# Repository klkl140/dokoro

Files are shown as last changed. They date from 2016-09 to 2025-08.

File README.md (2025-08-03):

# dokoro
a roboter for playing cards

##idea:
This device should replace a normal player.
It will be possible to play doko without having 4 people at the same table.
The device could act like a normal player, playing with its own intelligence or as an interface for an external player, for example sitting in timbuktu.
In addition it can be used for many different card games. Only a software problem.....

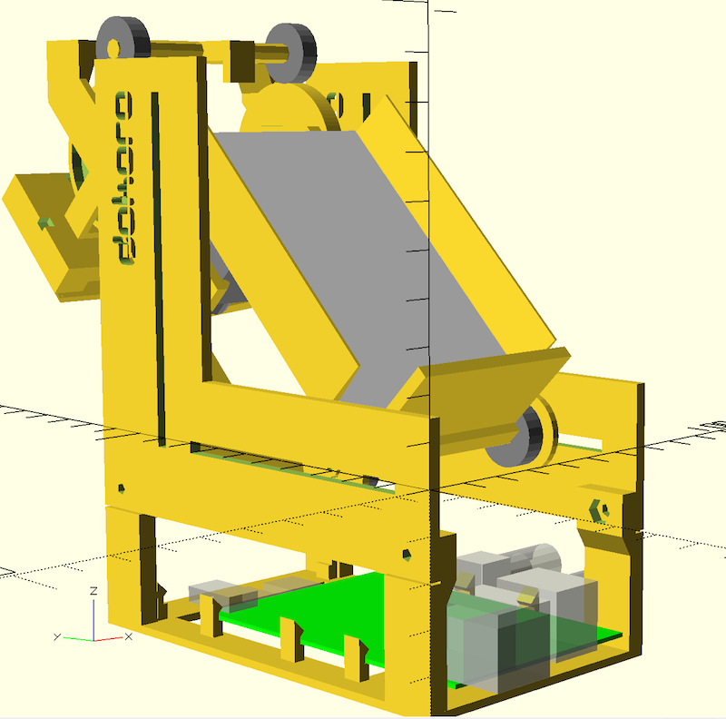
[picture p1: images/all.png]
dokoro openscad


##how it should work:
A human player is distributing the cards. The **dokoro** gets its cards placed in the cardholder.
For scanning these cards it has minimalistic hardware. One motor, one servo and a camera. The cards are moved in front of the camera one by one and an image-recognition is used. [Here](images/dokoroAnimation.mp4) a small animation.

After all the cards are recognized the play could start. A camera watches the playfield. This second view might be part of the first camera view using a mirror(?).
For the intelligence the project [FreeDoko](http://free-doko.sourceforge.net/de/FreeDoko.html) is planed to be used.

##the OpenSCAD construction uses:

###public libraries

[ParametricHerringboneGears.scad](https://github.com/beckdac/PARA/blob/master/ParametricHerringboneGears.scad)  
[pibase.scad](https://github.com/guyc/pi-box/blob/master/pibase.scad)  
[Font/font_DesignerBlock_lo.scad](https://github.com/QuackingPlums/QP_OpenSCAD_lib/blob/master/Makerbot%20font%20(Thingiverse%2022730)/font_DesignerBlock_lo.scad)  
[ISOThreadCust.scad](http://www.thingiverse.com/thing:311919)

###included files

CameraAdapter.scad, based on [piCameraMicroscopeAdapter.scad](https://github.com/luisibanez/ShapesFor3DPrinting/blob/master/OpenSCAD/piCameraMicroscopeAdapter.scad)  
9g_servo.scad  

##additional used parts:

* 4 ball-bearing 625	(at the rubber bands)
* 2 ball-bearing 683	(at the driving axis)
* 2 rubber-bands 130*4mm 
* [gear motor](http://www.ebay.de/itm/DC-1-5-12V-200rpm-Getriebe-Motor-elektrisch-Electric-Metal-Geared-Motor-3v-6v-9v-/231526128396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) 12V, 200 U/min
* [mini servo 9g SG90](http://www.ebay.de/itm/ELE-2x-Micro-Mini-Servo-SG90-RC-Servo-9g-Kabel-23cm-Neu-/222005349852) with some parts
* a metal axis 70*3mm
* a M3*76mm threaded rod
* Raspberry Pi with camera
* electronic for driving the motor and the servo (adafruit motor HAT)
* some screws and washers
	* 2* M3*8 + nut 		(at base frontside)
	* 2* M3*12 + nut 	(at the base backside)
	* 4* M3*6 countersunk +nuts (at the cardholder)
	* M3*25 + nut 		(at the camera arm)
	* 4* threaded rods M3*20 (at gears and driving wheels)
	* 2* washers M3 (at driving axis, between motorholder and driving wheel)

##electronics:
An Adafruit Motor HAT [circuit](https://cdn-learn.adafruit.com/assets/assets/000/022/655/original/raspberry_pi_schem1.png?1422045515) [instructions](https://learn.adafruit.com/adafruit-dc-and-stepper-motor-hat-for-raspberry-pi) is used for driving the DC-motor and the servo.
The DC motor is connected to M3, the servo is driven by the PWM of the Raspi with an aditional 5V regulator.

##other ideas:
A monitor could be used to show informations, a speaker for giving _valuable comments_. When the dokoro is used as an interface, these parts could be used to get a real connection to the remote player.  
The main focus is an easy to use device without any unnecessary interface. Speach recognition could be a good way to make some necessary inputs like anouncing solos, wedding, ... 

##current status:
The hardware seems to work. Cards could be moved by the driven rubber bands. The servo is mechanically able to move the cards and the whole flow of scanning the cards seems possible.  
FreeDoko could be compiled and the place of the missing interface is clear.  
Next step is connecting the raspbi to drive motor and servo.
Im searching for help in every project part. Help is given when someone tries to build his own example for development.  
__There is no working example available (up to now).__  

##challenges:
The reliability of the mechanic is not easy. All moving parts are constructed with ball bearings. The separation of cards might be difficult, especially when dirty cards will be allowed.  
Getting the interface to the Freedoko source might be easy. There is a network-player option which matches perfectly. The server has to the changed in the way that cards are not in the program but on the table.  
The use as an interface for external players will be a big place for software development.   

##licensing
The project is licenced using GPL2.

Enjoy it.... Klaus

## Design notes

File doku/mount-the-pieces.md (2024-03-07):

Start mounting cardholder (kartenauflage') to the (halterUnten) using 2x M3x6 countersunk screws and 2 nuts. 
Do the same with the motormount (halterOben)

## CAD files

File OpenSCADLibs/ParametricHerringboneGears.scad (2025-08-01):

// für den Dokoro verändert, das Original war https://www.thingiverse.com/thing:6544/files

// OpenSCAD Herringbone Wade's Gears Script
// (c) 2011, Christopher "ScribbleJ" Jansen
//
// Thanks to Greg Frost for his great "Involute Gears" script.
//
// Licensed under the BSD license.
include <MCAD/involute_gears.scad> 


// hier die Werte für die Vorschau
// WHAT TO GENERATE?
generate = 0;    // GENERATE BOTH GEARS FOR VIEWING
// generate = 1;    // GENERATE STEPPER GEAR FOR PRINTING
// generate = 2;    // GENERATE DRIVE GEAR FOR PRINTING

// OPTIONS COMMON TO BOTH GEARS:
distance_between_axels = 20;        // der Abstand zwischen den beiden Achsen
gear_h = 10;                        // die Breite des Zahnrads
gear_shaft_h = 4;                   // die zusaetzliche Breite des Schafts


// GEAR1 (SMALLER GEAR, STEPPER GEAR) OPTIONS:
// It's helpful to choose prime numbers for the gear teeth.
gear1_teeth = 10;                   // Anzahl der Zaehne des ersten Zahnrads
gear1_shaft_d = 3;  			    // die Bohrung fuer die Achse
// gear1 shaft assumed to fill entire gear.
// gear1 attaches by means of a captive nut and bolt (or actual setscrew)
gear1_setscrew_offset = 2.5;		// der Abstand der Befestigungsbohrung von der Shaft-Seite
gear1_setscrew_d      = 2.4;        // der Durchmesser der Bohrung		
// evtl eine Mutter fuer die Befestigungsschraube
gear1_captive_nut_d   = 0;      // das kleine Zahnrad hat keine Mutter. zu wenig Platz
gear1_captive_nut_r   = gear1_captive_nut_d/2;
gear1_captive_nut_h   = 0;    // Dicke M3 Mutter

// GEAR2 (LARGER GEAR, DRIVE SHAFT GEAR) OPTIONS:
gear2_teeth = 16;
gear2_shaft_d = 3;
// gear2 has settable outer shaft diameter.
gear2_shaft_outer_d   = 16;

// gear2 has a hex bolt set in it, is either a hobbed bolt or has the nifty hobbed gear from MBI on it.
gear2_bolt_hex_d      = 0;       //ohne sechskant
// gear2_bolt_sink: How far down the gear shaft the bolt head sits; measured as distance from drive end of gear.
gear2_bolt_sink       = 15;      //		
// gear2's shaft is a bridge above the hex bolt shaft; this creates 1/3bridge_helper_h sized steps at top of shaft to help bridging.  (so bridge_helper_h/3 should be > layer height to have any effect)
bridge_helper_h=3;

gear2_rim_margin = 0;
gear2_cut_circles  = 0;     // sind im Zahnrad-Körper Bohrungen zur Gewichtsreduzierung?

// gear2 setscrew option; not likely needed.
gear2_setscrew_offset = gear1_setscrew_offset;
gear2_setscrew_d      = gear1_setscrew_d;
// captive nut for the setscrew
gear2_captive_nut_d   = 5.6;      // Breite M3 Mutter
gear2_captive_nut_r   = gear1_captive_nut_d/2;
gear2_captive_nut_h   = 2.6;    // Dicke M3 Mutter

// Tolerances for geometry connections.
AT=0.02;
ST=AT*2;
TT=AT/2;

module bridge_helper(){
	difference(){
		translate([0,0,-bridge_helper_h/2])
            cylinder(d=gear2_bolt_hex_d+TT, h=bridge_helper_h+TT,$fn=6,center=true);
		translate([0,0,-bridge_helper_h/2])
            cube([gear2_bolt_hex_d+ST, gear2_shaft_d, bridge_helper_h+AT], center=true);
	}
}


module gearsbyteethanddistance(t1=13,t2=51, d=60, teethtwist=1, which=1){
	//cp = 360*d/(t1+t2);
    cp = 2*pi*d/(t1+t2);    // kl involute_gears has changed

	g1twist = 360 * teethtwist / t1;
	g2twist = 360 * teethtwist / t2;

	g1p_d  =  t1 * cp / 180;
	g2p_d  =  t2 * cp / 180;
	g1p_r   = g1p_d/2;
	g2p_r   = g2p_d/2;

	echo(str("Your small ", t1, "-toothed gear will be ", g1p_d, "mm across (plus 1 gear tooth size) (PR=", g1p_r,")"));
	echo(str("Your large ", t2, "-toothed gear will be ", g2p_d, "mm across (plus 1 gear tooth size) (PR=", g2p_r,")"));
	echo(str("Your minimum drive bolt length (to end of gear) is: ", gear2_bolt_sink+bridge_helper_h, "mm and your max is: ", gear_h+gear_shaft_h, "mm."));
	echo(str("Your gear mount axles should be ", d,"mm (", g1p_r+g2p_r,"mm calculated) from each other."));
    
    if(which == 1){ // GEAR 1 (das kleinere)
		difference(){
            union(){
                translate([0,0,(gear_h/2) - TT])
                    // der Teil des Zahnrads mit dem Schaft
                    gear(	twist = g1twist, 
                        number_of_teeth=t1,
                        circular_pitch=cp, 
                        gear_thickness = gear_shaft_h + (gear_h/2)+AT, 
                        rim_thickness = (gear_h/2)+AT, 
                        rim_width = 0,
                        hub_thickness = (gear_h/2)+AT, 
                        hub_diameter = 0,   //kl war hub_width das gibt es aber nicht mehr
                        bore_diameter=0); 
        
                translate([0,0,(gear_h/2) + AT])
                rotate([180,0,0]) 
                    // der zweite Teil des Zahnrads
                    gear(	twist = -g1twist, 
                        number_of_teeth=t1, 
                        circular_pitch=cp, 
                        gear_thickness = (gear_h/2)+AT, 
                        rim_thickness = (gear_h/2)+AT, 
                        hub_thickness = (gear_h/2)+AT, 
                        bore_diameter=0); 
            }
			//DIFFERENCE:
			//shafthole
			translate([0,0,-TT]) 
				cylinder(d=gear1_shaft_d, h=gear_h+gear_shaft_h+ST,$fn=10);

			//setscrew shaft
			translate([0,0,gear_h+gear_shaft_h-gear1_setscrew_offset])
				rotate([0,90,0])
				cylinder(d=2, h=10);    // h war g1p_r, das stimmt aber nicht mehr

			//setscrew captive nut
			translate([5.5/2, 0, gear_h+gear_shaft_h-gear1_captive_nut_r-gear1_setscrew_offset]) 
				translate([0,0,(gear1_captive_nut_r+gear1_setscrew_offset)/2])
					cube([gear1_captive_nut_h, gear1_captive_nut_d, gear1_captive_nut_r+gear1_setscrew_offset+ST],center=true);

        }
	} else {    //which!=1
		// GEAR 2
		difference(){
            union(){
                translate([0,0,(gear_h/2) - TT])
                    gear(	twist = -g2twist, 
                        number_of_teeth=t2, 
                        circular_pitch=cp, 
                        gear_thickness = gear_shaft_h + (gear_h/2)+AT, 
                        rim_thickness = (gear_h/2)+AT, 
                        rim_width = gear2_rim_margin,
                        hub_diameter = gear2_shaft_outer_d,
                        hub_thickness = (gear_h/2)+AT, 
                        bore_diameter=0,
                        circles = gear2_cut_circles); 
        
                translate([0,0,(gear_h/2) + AT])
                rotate([180,0,0]) 
                    gear(	twist = g2twist, 
                        number_of_teeth=t2, 
                        circular_pitch=cp, 
                        gear_thickness = (gear_h/2)+AT, 
                        rim_thickness = (gear_h/2)+AT, 
                        rim_width = gear2_rim_margin,
                        hub_diameter = gear2_shaft_outer_d,
                        hub_thickness = (gear_h/2)+AT, 
                        bore_diameter=0,
                        circles = gear2_cut_circles); 
            }
			//DIFFERENCE:
			//shafthole, fuer die Achse
			translate([0,0,-TT]) 
				cylinder(d=gear2_shaft_d, h=gear_h+gear_shaft_h+ST, $fn=10);

			//setscrew shaft, die Befestigungsschraube
			translate([0,0,gear_h+gear_shaft_h-gear2_setscrew_offset])
				rotate([0,90,0])
				cylinder(d=gear2_setscrew_d, h=gear2_shaft_outer_d);

			//setscrew captive nut
			translate([(gear2_shaft_outer_d)/4, 0, gear_h+gear_shaft_h-gear2_captive_nut_r-gear2_setscrew_offset]) 
				translate([0,0,(gear2_captive_nut_r+gear2_setscrew_offset)/2])
					cube([gear2_captive_nut_h, gear2_captive_nut_d, gear2_captive_nut_r+gear2_setscrew_offset+ST],center=true);

			//trim shaft
			difference(){
				translate([0,0,gear_h+AT]) cylinder(h=gear_shaft_h+ST, r=g2p_r);
				translate([0,0,gear_h])	cylinder(h=gear_shaft_h, d=gear2_shaft_outer_d);
			}

			//hex bolt shaft
			translate([0,0,-TT]) cylinder(d=gear2_bolt_hex_d, h=gear_h+gear_shaft_h-gear2_bolt_sink+AT,$fn=6);

		}

		// hex bolt shaft bridge aid.
		translate([0,0,gear_h+gear_shaft_h-gear2_bolt_sink])
			bridge_helper();
		translate([0,0,gear_h+gear_shaft_h-gear2_bolt_sink+bridge_helper_h/3])
			rotate([0,0,60]) bridge_helper();
		translate([0,0,gear_h+gear_shaft_h-gear2_bolt_sink+((bridge_helper_h/3)*2)])
			rotate([0,0,-60]) bridge_helper();
	}
}

t1 = gear1_teeth;
t2 = gear2_teeth;
cp = 360*distance_between_axels/(t1+t2);
g1p_d  =  t1 * cp / 180;
g2p_d  =  t2 * cp / 180;
g1p_r   = g1p_d/2;
g2p_r   = g2p_d/2;

if(generate != 2){  // 0 oder 1
	translate([-g1p_r,0,0])gearsbyteethanddistance(t1 = gear1_teeth, t2=gear2_teeth, d=distance_between_axels, which=1);
}
if(generate != 1){   // 0 oder 2
	translate([g2p_r,0,0])gearsbyteethanddistance(t1 = gear1_teeth, t2=gear2_teeth, d=distance_between_axels, which=2);
}

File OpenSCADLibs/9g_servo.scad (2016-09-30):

drehachseR = 2.35;
servoX = 23;
servoY = 12.5;
servoZ = 22.5;

offsetBefestigungZ=4;   // wie weit ist die Unterkante der Befestigungsplatte von der Mittelachse entfernt
befestigungZ = 2.7;

module 9g_motor(){
	difference(){			
		union(){
			color("Gray") cube([servoX,servoY,servoZ], center=true);
			befestigungZ = 2.7;
            color("Gray") translate([0,0,offsetBefestigungZ+befestigungZ/2])
                cube([32,12,befestigungZ], center=true);
			color("Gray") translate([5.5,0,2.75]) cylinder(r=6, h=25.75, $fn=20, center=true);
			color("Gray") translate([-.5,0,2.75]) cylinder(r=1, h=25.75, $fn=20, center=true);
			color("Gray") translate([-1,0,2.75]) cube([5,5.6,24.5], center=true);		
			color("white") translate([5.5,0,3.65]) cylinder(r=2.35, h=29.25, $fn=20, center=true);
		}
		// die Abschrägung gibt es nicht immer
        //translate([10,0,-11]) rotate([0,-30,0]) cube([8,13,4], center=true);
		for ( hole = [14,-14] ){
			translate([hole,0,5]) cylinder(r=2.2, h=4, $fn=20, center=true);
		}	
	}
}

module 9g_arm(laenge,winkel){
    dicke = 3;
    rAchse = 4;
    rEnde = 2;
    #translate([5.4,0,16])rotate([0,0,winkel]){
        difference(){
            union(){
                translate([0,0,-2]) cylinder(r=rAchse, h=dicke+2);
                linear_extrude(height = dicke, convexity = 10)
                    polygon(points=[[0,rAchse],[0,-rAchse],[laenge,rEnde],[laenge,-rEnde]]
                        , paths=[[0,1,3,2]]);
                translate([laenge,0,0]) cylinder(r=rEnde, h=dicke);
            }
            // die Achse
            translate([0,0,-2.1]) cylinder(r=drehachseR, h=2);
            // das Loch zur Befestigung der Hebelstange
            translate([laenge,0,-.1]) cylinder(d=1.5, h=dicke+.2);
        }
    }
}

module 9g_holder(){
    luft = .3;
    dicke = 3;
    hoehe = servoZ; // der Halter ist so hoch wie das Servo
    naseY = 3.3;    // soll etwas unter Spannung sein, war 3.5
    difference(){
        union(){
            // lange Seite
            translate([-servoX/2-luft,servoY/2+luft,servoZ/2-hoehe])
                cube([servoX+2*luft,dicke,hoehe]);
            // kurze Seiten
            seiteY = servoY+dicke+luft+naseY-1; // jetzt 1mm kürzer
            hoeheS=hoehe-7; //die Federklammern sind auf der ganzen Höhe zu fest.
                            //das Kabel muss auch raus geführt werden
            for(x=[-servoX/2-dicke-luft, servoX/2+luft]){
                translate([x,-servoY/2-naseY+1,servoZ/2-hoeheS]) cube([dicke,seiteY,hoeheS]);
            }
            // die Haltenasen
            dicke2=dicke*.9;   // war 1.1
            for(x=[servoX/2+luft,-servoX/2-luft]){
                //Y jetzt 1mm kuerzer (+1)
                translate([x,-servoY/2-naseY+1,servoZ/2-hoeheS])
                    rotate([0,0,45]) cube([dicke2,dicke2,hoeheS]);
            }
        }
        // der Schlitz für die Befestigung
        schlitzZ = befestigungZ+luft;
        schlitzY = servoY+naseY+.1;
        gesamtX = servoX+2*luft+2*dicke;
        gesamtY = dicke+luft+servoY+naseY;
        translate([-gesamtX/2-.1,-schlitzY+servoY/2,offsetBefestigungZ])
            cube([gesamtX+.2,schlitzY,schlitzZ]);
    }
}

9g_motor();
9g_arm(laenge=20,winkel=90);
9g_holder();

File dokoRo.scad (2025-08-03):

// der DoppelKopfRoboter
// (c) Klaus Kloos 160630
//
// die 0-Achse liegt in der Mitte der horizontalen Winkelverstellung

use <pibase.scad>                                   // pi board und halter
use <OpenSCADLibs/ParametricHerringboneGears.scad>  // erzeugt die Zahnräder aufgrund von Zahnanzahl und Abstand
use <OpenSCADLibs/servo9g.scad>
use <OpenSCADLibs/CameraAdapter.scad>               // fuer die Raspberry-Kamera
use <Font/font_DesignerBlock_lo.scad>
use <ISOThreadCust.scad>
use <MCAD/bearing.scad>

// neu, noch nicht gedruckt
//
// was fehlt noch?
// -Kabelbefestigung
//
// was soll gemalt werden?
paintAll3D = 0;                         // alle Teile an ihren Positionen evtl mit Animation
paintAll2D = 0;                         // dies kann mit einem Laser gemacht werden

if(!paintAll3D){         // hier kommen die einzelnen Teile für die Fertigung
    //seitenwand();						// 2* die Seiten
    //cardholder();                     // kartenauflage, hier liegen die Karten
    //separierer(separierer);
    //scheibeHalterUnten();             // 2* neben den Kugellagern zur Führung des Gummis
    rotate([180,0,0]) halterUnten();  // mit den unteren beiden Kugellagern
    //rotate([0,180,0]) motorKlemme(); // hiermit wird der Motor befestigt
    //antriebsRad();  // 2* die oberen Antriebsräder
    //halterOben(0);                    // ohne Antrieb
    //bothGears();                      // beide Zahnräder, fürs Drucken Auflösung einstellen!
    //rotate([45,0,0])anpressrolle();   // der mit dem Servo bewegte Greifer
    //raspbiHalter();                   // der Halter für den Raspberry
    //kameraHalter();                   // Kamera fuer den Blick auf die Karten
	//piCameraBackCover(-0.2);	        // der Schiebedeckel zur Kamera
    //motor();                          // Dummy des Motors, muss nicht gedruckt werden
}

// Animation
t_cardUp = .3;                      // die Zeit in der die Karte nach oben fährt
t_drehung = .5;                     // nach dieser Zeit ist die Drehung fertig
t_cardUp2 = .7;                     // die zweite Bewegung der Karte

cardRaw = [59, 90, 0.5];            // eine Spielkarte
card = [cardRaw.x+1,cardRaw.y+3];   // mit ein wenig Spiel

gummiB = 4+.5;                      // Breite des Gummies + Freiraum
gummiD = 1;                         // die Dicke des Gummis

swSchenkelH = 35;                   // die Breite des horizontalen Seitenwand-Schenkels, in der Mitte der Schlitz
swAddY = 5;                         // auf der Seite der Antriebsräder etwas breiter für die Schrift
swSchenkelV = swSchenkelH+swAddY;   // und damit der Servohebel geführt wird
// die Abmasse der flach liegende Seitenwand
seitenwand = [card.y+swSchenkelH/2+swAddY   // horizontal    
    , card.y+swSchenkelH/2                  // vertical
    , 3];                                   // dicke

auflageD = 3;                       // cardholder und der obere Halter
breiteStegUnten = 15;
KL625frei = bearingWidth(model=625)+1; // ein wenig Spiel
rolleObenD = 38;                    // Duchmesser der Antriebsrolle oben
rolleObenB = gummiB+.5;             // die Breite
bohrungHalter = 3.5;                // fuer beide Halter, war 3
bohrungHalterX = 12;                // jeweils der Abstand vom Rand
screwholeBottomY = 10;
screwholeTopY = 81;
achseAntrieb = 3;                   // muss auch in ParametricHerringboneGears eingestellt werden
motorHalter=[17,20];                // der Bock an dem der Motor befestigt wird [x,y]
motorHalterBohrungD=2.5;            // die Befestigung des oberen Stuecks
motorZ = 10;                        // die Dicke des Motors 
breiteStuetzeRB=14;                 // die Stützen des Raspbi-Halters
RBueberlappung=10;                  // Überlappung zwischen Raspbi-Halter und Seitenwand
RBueberlappungD=2;                  // das Material neben der Seitenplatte
armServorolleD=2;                   // die Dicke des beweglichen Arms und bestimmt damit auch die Gesamtbreite 
separiererY = 8;                    // oben haben wir 8mm um einen Kartenseparierer unterzubringen
keilH = 15;                         // für den Kartenhalter seitlich
achseMotorD=20;                     // zwischen Motor und Antriebsachse, y-Richtung
achseMotorDm=19.8;                  // die dort liegenden Zahnräder brauchen etwas Spiel
uebersetzung = [10,16];             // die beiden Antriebszahnräder, war [15/15]
                                    // [10,16] läuft gleichmaessiger, mehr Kraft
        
//berechnetes
abstandSeiten = card.x+2*armServorolleD+1;  // der Abstand der beiden Seiten auf der Innenseite
                                            // etwas Spiel für die Mechanik, innen gemessen
nebenKarten = (abstandSeiten-card.x)/2;     // der Platz neben den Karten. hier liegen die seitlichen
                                            // Haltekeile, die Führungsscheiben und der Servoarm
separierer = [abstandSeiten-2*nebenKarten,separiererY,keilH];

bM3 = 2.6;          // die Dicke der Mutter, 2.5 war zuwenig, 2.7 aber nicht fest
holeM3 = 3.5;       // da passt die Schraube durch
module tascheM3(){
    b=6;            // der Durchmesser für die 6-eckige Mutter
    cylinder(d=b, h=bM3, $fn=6);
    b1=b*.9;        // die zur Mutter gehörende Breite
    translate([-10,-b1/2,0])cube([10,b1,bM3]);
}

// eine Bohrung fuer eine gesenkte Schraube
module countersunkHole(bohrungD,dicke){
    union(){
        cylinder((dicke+.5)/2, d=bohrungD, $fn=15);
        translate([0,0,(dicke+.2)/2])
            cylinder((dicke+.5)/2, r1=bohrungD/2, r2=bohrungD, $fn=15);
    }
}

module langloch(l, breite, dicke){
    for(pos=[0,-l])translate([pos,0,0])cylinder(d=breite,h=dicke,$fn=20);
    translate([-l,-breite/2,0])cube([l,breite,dicke]);
 }

// eine verschiebbare Mutter
module slotM3(dicke, laenge){
    mutterX = 5.5;  // die Mutter soll sich verschieben lassen
    translate([-holeM3/2,0,-.1]) union(){
        //oben soll Platz für die Mutter sein
        cube([holeM3,laenge,dicke/2+.1]);
        //die andere Hälfte bleibt mit der Bohrung
        translate([-(mutterX-holeM3)/2,0,dicke/2]) cube([mutterX,laenge,dicke/2+.2]);
    }
}

module seitenwand(){
    schlitz=3;                          // die Breite der Schlitze für die Winkelverstellung
    hSchlitzLaenge=card.y-8;            // der horizontale Schlitz
    halbeSW = swSchenkelH/2;
    difference(){
        linear_extrude(height = seitenwand.z, convexity = 10)
            polygon(points=[[0,0]
                        ,[seitenwand.x,0],[seitenwand.x,swSchenkelH]
                        ,[swSchenkelV,swSchenkelH]
                        ,[swSchenkelV,seitenwand.y]
                        ,[0,seitenwand.y]]);
        translate([15,hSchlitzLaenge-3,-.1]) rotate([0,0,90])
            difference(){
                label("dokoro", size=4, height=seitenwand.z+.2);
                // mit einem Steg fixieren wir die haltlosen Innen-Stücke der 'O's
                translate([-18,1.8,0]) cube([45,1,seitenwand.z+.2]);
            }
        // der vertikale Schlitz
        translate([halbeSW+swAddY,halbeSW,-.1]) cube([schlitz,hSchlitzLaenge,seitenwand.z+.2]);
        // der horizontale Schlitz
        translate([swSchenkelV-5,halbeSW,-.1]) cube([70,schlitz,seitenwand.z+.2]);
        // die Löcher für die Befestigung des Raspi-Halters
        for(i=[breiteStuetzeRB/2,seitenwand.y-breiteStuetzeRB/2+swAddY]){
            translate([i,RBueberlappung/2,-.1])
                cylinder(d=holeM3,h=seitenwand.z+.2, $fn=20);
        }
    }
}
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

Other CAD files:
OpenSCADLibs/servo9g.scad
OpenSCADLibs/CameraAdapter.scad

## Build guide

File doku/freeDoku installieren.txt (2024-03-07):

Kompilieren von FreeDoku 0.7.8
-MacPorts installiert, neues Shell-Fenster
-sudo port install pkgconfig
-sudo port install gtkmm 
der Compiler meckert über ein fehlendes Package freealut

installation freealut (fur Sound)
./autogen.sh funktionierte erst nachdem die LineEndings angepasst waren
./configure funktioniert dann auch
trotzdem funktioniert das make nicht
OpenAL_Installer_OSX installiert, kein Erfolg

compilieren mit
make compile USE_SOUND_ALUT=false

wenn fertig compiliert starten durch
./FreeDoko

——————
FreeDoko 0.7.13
package gtkmm-2.4 fehlt
sudo port selfupdate
sudo port upgrade outdated
sudo port install gtkmm
sudo port install freealut
sudo port install openal		// hierfür muss xcode Vollversion installiert sein
sudo port install gnet2
make compile USE_SOUND_ALUT=false
-> funktioniert

Dann mit dem Shell-Skript FreeDoko_OSX starten. Dieses muss im Ordner src liegen.

Der fehlende Ton liegt an openal, das sich nicht mit MacPorts installieren lässt
Deshalb diese Variante:
git clone git://repo.or.cz/openal-soft.git
cd openal-soft/build/
cmake ..
make
make install
export PKG_CONFIG_PATH=/Users/klkl/Documents/freeDoko/FreeDoko_0.7.13/openal-soft/build
cp libopenal.dylib ../../src/
cd ../..
-> und bauen -> funktioniert

——————
0.7.14
Z:\Documents\freeDoko\FreeDoko_0.7.14\src\text\help.string help_string wieder auf alte Version -> hilft weiter
static_cast<string>(*::version) funktioniert nicht, ersetzen durch ::version->number_to_string()
Z:\Documents\freeDoko\FreeDoko_0.7.14\src\ui\gtkmm\main_window.cpp
Z:\Documents\freeDoko\FreeDoko_0.7.14\src\ui\gtkmm\support.cpp
Z:\Documents\freeDoko\FreeDoko_0.7.14\src\ui\gtkmm\about.cpp
Z:\Documents\freeDoko\FreeDoko_0.7.14\src\ui\gtkmm\bug_report_replay.cpp 524
->funktioniert!

Text-Interface
make compile USE_SOUND_ALUT=false USE_UI_GTKMM=false USE_UI_TEXT=true
diverse Fehler in ui/text/ui.h ->class Party; herausgenommen in ui/ui.h definiert, darf nicht in die Klasse

Debug-Ausgaben
start mit ./FreeDoko —debug

—Fragen
command.cpp Änderung um unsinnigen output im Terminal zu verhindern
void
Sound::Command::play(Position const& position,
                   string const& voice, Type const type)
{
    string path = Sound::filename(position, voice, type);
    if(path.length()){
        system((PLAY_SOUND_COMMAND + (" " + path) + " >/dev/null &").c_str());
    }
}
—
string filename(Sound::Type const type); in filenameBase umbenennen
—
text und name durch einen Array-Zugriff ersetzt
—
espeak unter Linux hat gleiche Funktionalität
——

subversion

Dateien auschecken
	svn checkout svn://svn.gna.org/svn/freedoko/trunk
	cd trunk/src
	make compile USE_SOUND_ALUT=false
im ordner trunk:
	svn up um upzudaten
	svn diff um Unterschiede zu finden, funzt auch ohne Netz
	svn revert --depth=infinity * um alle gemachten Änderungen zu verwerfen

— Version 0.7.15 svn
sudo port install gtkmm3
verwendet -std=c++14 was der aktuelle compiler nicht kann
in Makefile.os -std=c++14 durch -std=c++1y ersetzen -> funktioniert

—— gemachte Änderungen
sound/command.cpp: OSX Soundausgabe, mehrere Stimmen

es gibt die drei verschiedenen Sound-Ausgabe
USE_SOUND_ALUT		// funktioniert noch nicht
USE_SOUND_COMMAND	// braucht ein Prg das Texte vorliesst, unter OSX ‚say -v Yannick "hallo"‘
USE_SOUND_PLAYSOUND	// wohl für Windows

make USE_SOUND_ALUT=false USE_SOUND_COMMAND=true	// funktioniert, muss bei Aenderungen aber komplett gebaut werden	

OSX 10.11 FreeDoko 0.7.15
svn checkout svn://svn.gna.org/svn/freedoko/trunk
cd trunk
make compile USE_SOUND_ALUT=false
es fehlt gtkmm3, dazu braucht es port und ein Passwort….

0.7.16 Anleitung
https://sourceforge.net/p/free-doko/discussion/118377/thread/d4837eb962/

0.7.26 unter 10.15
git clone https://gitlab.com/dknof/FreeDoko.git
cd FreeDoko
make compile USE_SOUND_ALUT=false
--
in diesen Dateien gibt es noch Probleme die mit einem (unsigned) cast behoben werden können
/player/ai/announcements/normal/contra.cpp
/player/ai/announcements/normal/re.cpp
/player/ai/announcements/poverty/contra.cpp
/player/ai/solo_decision/meatless.cpp
./ui/gtkmm/icons.cpp
--

Sonstiges:
-es gibt noch ein anderes Projekt
https://sourceforge.net/projects/jdoko/?source=typ_redirect
Java, netbeans, server/client, scheint unfertig, 3 Jahre alt

OSX App
https://stackoverflow.com/questions/1596945/building-osx-app-bundle
https://github.com/auriamg/macdylibbundler/
Platypus baut OSX Apps
/po ist die Übersetzung

Das FreeDoko Executable ist gegen die mit MacPorts importierten dylibs gebaut. Die müssen auch in das App-Package
https://stackoverflow.com/questions/33333628/how-can-i-bundle-a-dylib-within-a-mac-app-bundle-in-qt
sudo port install dylibbundler
dylibbundler -od -b -x FreeDoko -d libs		// erzeugt einen Ordner libs der alle dylibs enthält und ändert die App entsprechend
Dieser Ordner muss in den Ordner oberhalb der App

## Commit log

2016-11-05 bild kleiner
    [dokoRo.scad]
2019-01-27 Antriebsräder mit Madenschrauben
    [dokoRo.scad]
2024-03-07 greater holes in cardholder
    Bohrungen cardholder größer, kartenAuflage in cardholder umbenannt
    [dokoRo.scad]
2024-03-07 Update README.md
    add screws
2024-03-08 m3 vereinfacht
    Bohrungen M3 vereinfacht
    [dokoRo.scad]
2024-03-08 kleinkram
    kleinkram
    [dokoRo.scad]
2025-07-11 9g_servo durch servo9g ersetzt, kleine Fehler
    [dokoRo.scad]
2025-07-11 9g_servo durch servo9g ersetzt
    [servo9g.scad]
2025-07-11 card als Array
    [dokoRo.scad]
2025-07-11 motorhalter als Array
    [dokoRo.scad]
2025-07-11 seitenHalterOben mit Parameter Array
    [dokoRo.scad]
2025-07-11 Fehler bei der Grösse des Motorblocks behoben, Kleinkram
    [dokoRo.scad]
2025-07-11 MCAD/bearing und weiter Vereinfachungen
    [dokoRo.scad]
2025-07-11 noch mehr MCAD/bearing
    [dokoRo.scad]
2025-07-11 noch mehr MCAD/bearing Kugellager.scad weg
    [Kugellager.scad]
2025-07-11 noch weniger doppelte Aufrufe
    [dokoRo.scad]
2025-07-11 ParametricHerringboneGears.scad fehlte
    [ParametricHerringboneGears.scad]
2025-07-11 ParametricHerringboneGears.scad fehltecd
    [dokoRo.scad]
2025-07-11 nebenKarten für alle
    [dokoRo.scad]
2025-07-11 Servo mit Arm im Winkel darstellbar
    [servo9g.scad]
2025-07-11 Animation mit Servoarm
    [dokoRo.scad]
2025-07-11 kamerahalter befestigung nur noch metrisch
    [dokoRo.scad]
2025-07-24 Update servo9g.scad
    kommentar
    [servo9g.scad]
2025-07-24 Update dokoRo.scad
    übersetzung geändert, Kleinkram
    [dokoRo.scad]
2025-07-24 Update dokoRo.scad
    Befestigung oben mit metrischen Schrauben
    [dokoRo.scad]
2025-07-28 Update ParametricHerringboneGears.scad
    eine befestigungsschraube fehlte
    [ParametricHerringboneGears.scad]
2025-07-28 Update dokoRo.scad
    separierer und anderes
    [dokoRo.scad]
2025-07-28 Update dokoRo.scad
    langloch als funktion
    [dokoRo.scad]
2025-07-30 Update ParametricHerringboneGears.scad
    jetzt mit Muttern
    [ParametricHerringboneGears.scad]
2025-07-30 Update dokoRo.scad
    Seitenwand überarbeitet
    [dokoRo.scad]
2025-07-30 Update dokoRo.scad
    Servohalter wieder nach innen verschoben
    [dokoRo.scad]
2025-08-01 Update ParametricHerringboneGears.scad
    Mutter nur beim grossen Zahnrad
    [ParametricHerringboneGears.scad]
2025-08-01 Update dokoRo.scad
    motorZ richtig
    [dokoRo.scad]
2025-08-03 Update dokoRo.scad
    Motorhalter kürzer, Kartenhalter kürzer
    [dokoRo.scad]
